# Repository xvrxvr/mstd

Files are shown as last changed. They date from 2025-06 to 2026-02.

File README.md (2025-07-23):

# UKNC-BK MSTD+

**UKNC-BK MSTD+** is a universal external mass storage device designed to work simultaneously with two Soviet-era 16-bit computers from the 1980s: the *Elektronika BK0010/0011* and the *Elektronika MS0511 (UKNC)*.

<https://en.wikipedia.org/wiki/Electronika_BK>

<https://en.wikipedia.org/wiki/UKNC>

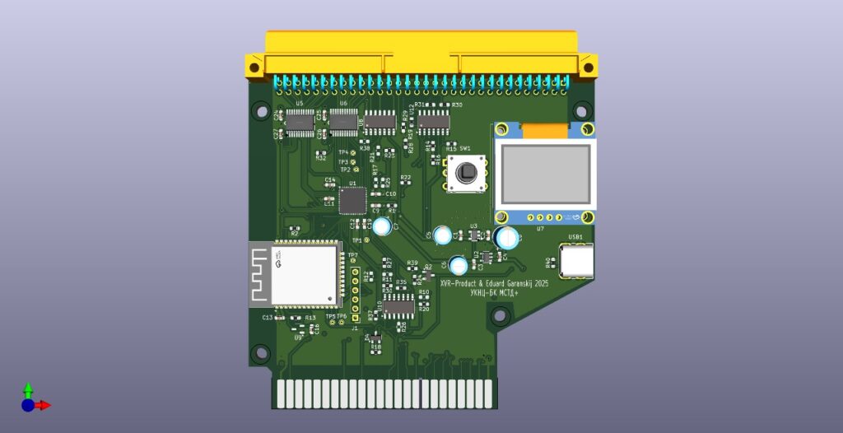
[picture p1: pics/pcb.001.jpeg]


Both machines are based on the K1801 series CPUs, which are compatible with the DEC PDP-11 instruction set and use a simplified version of the DEC UNIBUS-like MPI system bus.\
[Wiki MPI BUS (In Russian)](https://ru.wikipedia.org/wiki/%D0%9C%D0%B0%D0%B3%D0%B8%D1%81%D1%82%D1%80%D0%B0%D0%BB%D1%8C%D0%BD%D1%8B%D0%B9_%D0%BF%D0%B0%D1%80%D0%B0%D0%BB%D0%BB%D0%B5%D0%BB%D1%8C%D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)

While the physical connectors differ between the two systems (UKNC using an extended version), they are logically compatible.

To accommodate both, the board features two separate bus connectors—one for each computer.

**Key Features**

*	**Hardware**: Built on an ICE40UP5K FPGA and an ESP32 microcontroller.
*	**Display**: Includes a small OLED screen for disk image selection and device configuration.
*	**Storage**: Does **not** use SD cards. Disk images are uploaded via **Wi-Fi** and stored in the device’s internal Flash memory.
*	**Power**: USB-C connector is used **only for additional power supply**.
*	**Compatibility**: Works with both BK0010/BK0011 and UKNC (MS0511) computers.

**Current Status (July 2027)**

*	Custom PCB designed in KiCad
*	Hardware assembly and testing in progress\
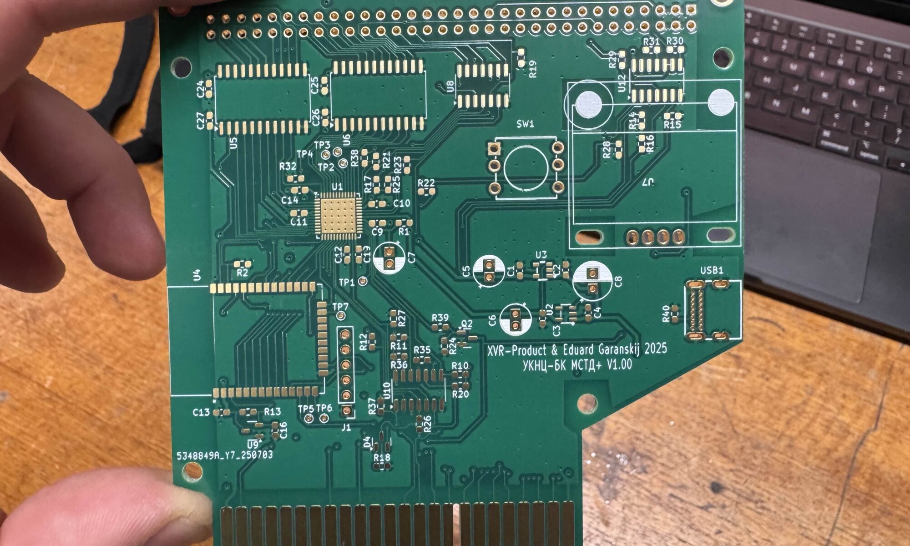
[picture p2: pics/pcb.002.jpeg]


# **Additional Resources**

##	📺 **Elektronika MS0511 (UKNC) Review**

*The Clueless Engineer*

[Watch on YouTube](https://www.youtube.com/watch?v=qSb77XoAgPw&ab_channel=TheCluelessEngineer)

##	📚 **DEC PDP-11 Instruction Set Reference**

Official DEC documentation archive

[View PDF](https://www.bitsavers.org/pdf/dec/pdp11/handbooks/PDP11_Handbook_1981.pdf)

##	🖥️ **UKNC Emulator**

Cross-platform emulator for Elektronika MS0511

[GitHub Repository](https://github.com/sergev/ukncbtl)

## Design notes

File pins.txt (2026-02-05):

ESP32

IO36 - Sensor-VP - CI0 Left
IO39 - Sensor-VN - CI1 Hit
IO34 - CI2             Up
IO35 - CI3             Right
IO32 - CIO0            Down

IO33 - CIO1            I2C-SCL
IO25 - CIO2            I2C-SDA

IO26 - CIO3            ROM-DIS3 (MON)   OUT  (1 - disable)
IO27 - CIO4            S-UKNC           IN
IO13 - CIO5            ROM-DIS1 (BAS)   OUT  (1 - disable)
IO21 - CIO6            S-BK             IN
IO19 - CIO7            ROM-DIS2 (BAS3)  OUT  (1 - disable)

    ESP -> FPGA
IO23 - CDONE           FPGA -> ESP32   (OC)
IO22 - ~CRESET         ESP32 -> FPGA
IO18 - IOB-29b
IO5  - IOB-31b
IO17 - IOB-32a-SPI_SO
IO16 - IPB-33b-SPI_SI
IO4  - IOB-34a-SPI_SCK
IO2  - IOB-35b-SPI_SS

FPGA
IOB-13b - FIO0            D3
IOB-16a - FIO1            D2
IOB-18a - FIO2            D1
IOB-20a - FIO3            D0
IOB-22a - FIO4            T/~R    OUT  [0 - read (BK -> FPGA), 1 - write (FPGA -> BK)]
IOB-23b - FIO5            WTB     IN
IOB-24a - FIO6            RUN     OUT  (1 - active)
ION-25b-G3 - FIO7         CE3     IN
IOB-0a                    D9
IOB-2a                    D8
IOB-3b-G6                 D11
IOB-4a                    D7
IOB-5b                    D10
IOB-6a                    D6
IOB-8a                    D4
IOB-9b                    D5

IOT-37a        INIT        OUT   (1 - reset)
IOT-38b        ROM-CE1     IN
IOT-39a        ROM-CE2     IN
IOT-41a        IRQ         OUT   (1 - IRQ)
IOT-42b        RPLY        OUT   (1 - Replay strobe)
IOT-43a        DOUT        IN
IOT-44b        DIN         IN
IOT-45a-G1     SYNC        IN
IOT-46b-G0     IAKN        IN
IOT-48b        D15
IOT-49a        D12
IOT-50b        D14
IOT-51a        D13

=======================================
FPGA config (pp31-34):

1. CRESET <= 0, SPI_SS <= 0, SPI_SCK <= 1
2. wait 200nS
3. CRESET <= 1
4. wait > 1.2mS (no SCK)
5. SPI_SS <= 1
6. Run SCK for 8 ticks
7. SPI_SS <= 0
8. Send data:
    MSB first, on faling edge of SCK
9. SPI_SS <= 1
10. wait for CDONE => 1  (still generating clocks). Max 100 clocks
11. send 49 more SCK ticks

SCK Freq - 1-25 MHz
=======================================

C sensor (5 wire flat cable) - 100-130pF/50cm (dry). Wet 130->330 pF
C sensor (PCB) - 270pF

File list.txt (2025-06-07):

iCE40UP5K-SG48I        C2678152  1340 6.5/1, 5.53/10

ESP32-WROOM-32E-N16    C701343   1774 4.4/1, 3.83/10
ESP32-WROOM-32D-N16    C529578   1148 4.3/1, 3.72/10

ESP32-S3-WROOM-1-N16R2 C2913205  4460 5.8/1, 4.86/10
ESP32-S3-WROOM-1-N16   C2913199   465 5.3/1, 4.5/10

LDO 1.2:
JTD6206-12             C42443422 2050  0.0067/50
LR8103A-T12            C7501644  53440 0.0218/20
TLV70212DBVR           C81462    28635 0.1031/5, 0.0807/50

LDO 3.3:    (500mA - 0.85W)
4A2D (CE is Hi)        C2832127  23920 0.0299/20, 500mA
TMI6050-33 (CE is Hi)  C911079   1698  0.0333/3, 0.0268/30  600mA   0.6W   (1.1W on 3x5 sm PCB)     <<<
AP7361C-33Y5-13        C460397   1115  0.1755/5  1.5A, 0.8W

SW:
HX809TDBZRG            C5145364  4240  0.0306/20

СНП58-64/94x9В-23-2-В (вилка)

74HCT4066D,118         C5998 4245  0.24/5

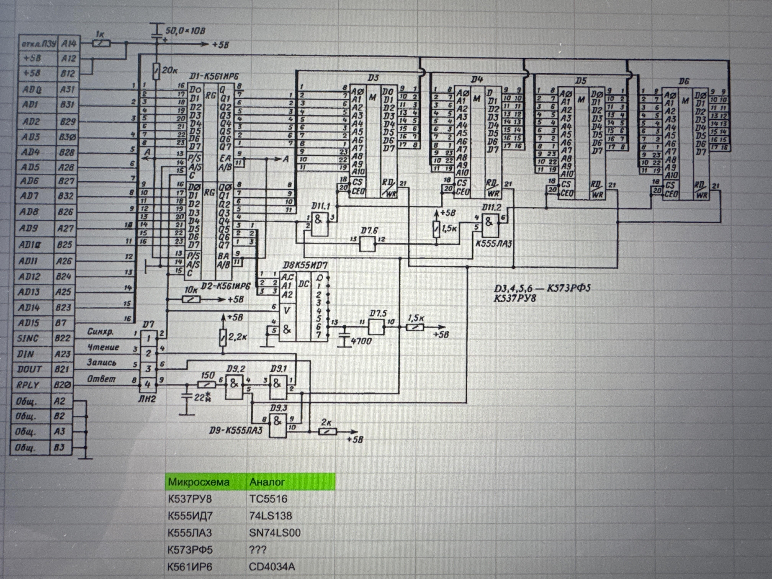
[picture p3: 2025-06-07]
mstd.jpg

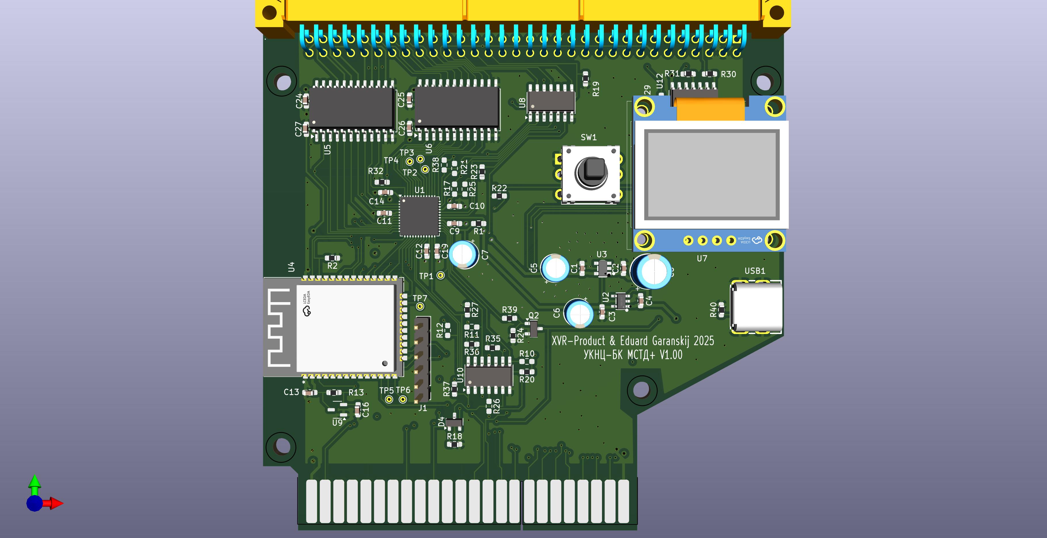
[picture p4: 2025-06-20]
mstd/mstd.jpg

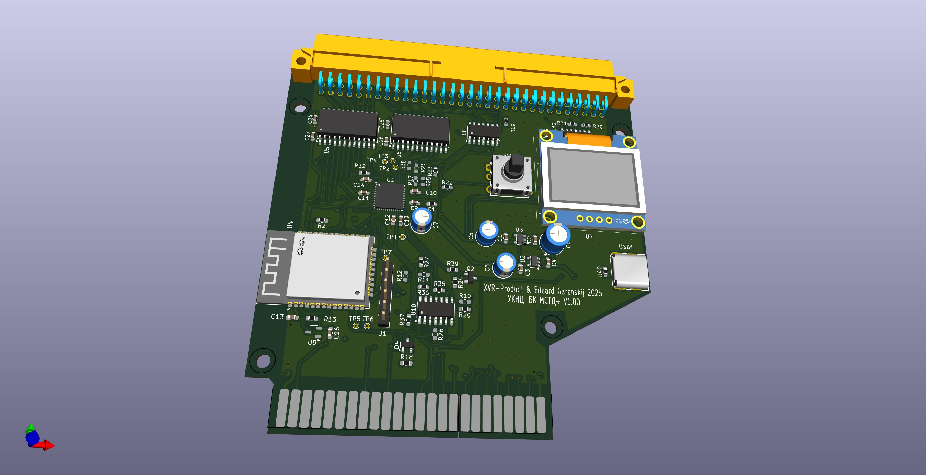
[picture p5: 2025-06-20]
mstd/mstd1.jpg

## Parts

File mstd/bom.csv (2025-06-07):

Reference | Value | Qty | DNP
C1,C2,C3,C4,C9,C10,C11,C12,C13,C14,C17,C19,C22,C23,C24,C25,C26,C27 | 1.0 | 18
C5 | 20x16V | 1
C6,C7 | 10x16V | 2
C8 | 100x16V | 1
C20 | 10.0x16V | 1
D4 | BAT54C | 1
J1 | PROG | 1
J2 | Barrel_Jack | 1
Q1 | SI2301CDS-T1-GE3 | 1
Q2 | 2N7002 | 1
R1 | 100 | 1
R2,R5,R6,R7,R8,R9,R13,R20,R22 | 10K | 9
R3,R4 | 2K2 | 2
R10,R11,R12,R17,R21,R25,R26,R38 | 1K | 8 | DNP
R14,R15,R16,R18,R19,R23,R24,R27,R28,R32,R34,R35,R36,R37 | 100K | 14
R29,R30,R31 | R | 3
R33 | 1K | 1
R39 | 200 | 1
SW1 | TSX101G100-250 | 1
U1 | ICE40UP5K-SG48ITR | 1
U2 | TLV70212DBVR | 1
U3 | TMI6050-33 | 1
U4 | ESP32-WROOM-32E-N16 | 1
U5,U6 | 74LVX3245MTCX | 2
U7 | SSD1306 OLED | 1
U8,U10 | 74HCT05 | 2
U9 | APX803S-31SA | 1 | DNP
U12 | 74HCT4066 | 1
X3,X4 | ~ | 2

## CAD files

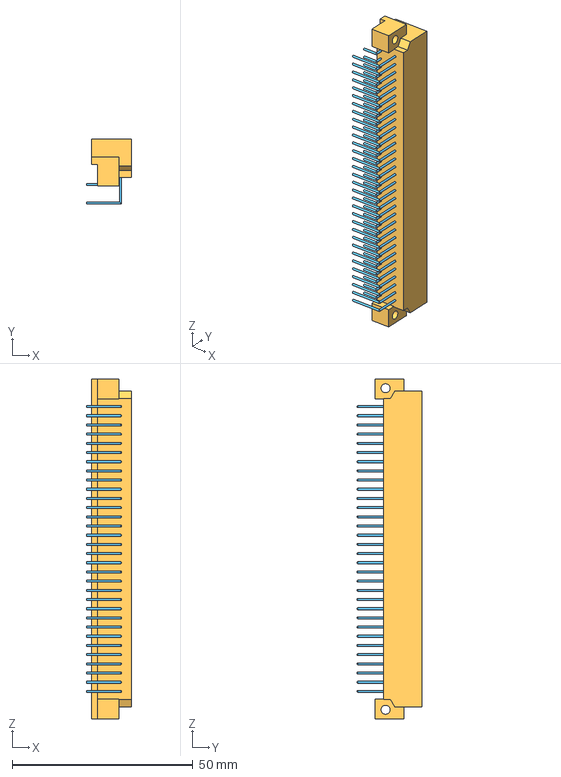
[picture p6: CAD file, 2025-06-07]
mstd/3D/09031646951.stp
12.4 x 18.0 x 94.0 mm

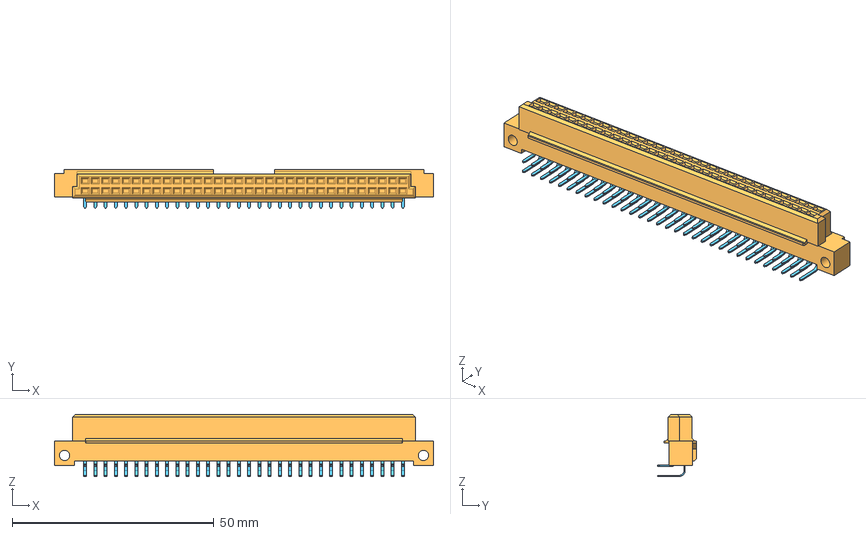
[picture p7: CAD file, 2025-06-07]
mstd/3D/09722646801.stp
93.9 x 9.59 x 15.4 mm

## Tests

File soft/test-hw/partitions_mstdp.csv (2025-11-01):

# Name | Type | SubType | Offset | Size | Flags
# Note: if you have increased the bootloader size | make sure to update the offsets to avoid overlap
nvs | data | nvs | 0x9000 | 0x6000
phy_init | data | phy | 0xf000 | 0x1000
otadata | data | ota | 0x10000 | 0x2000
config | data | undefined | 0x12000 | 0x1000
# Hole
loader | app | test |  | 1M
ota_0 | app | ota_0 |  | 3M
ota_1 | app | ota_1 |  | 3M
storage | data | spiffs |  | -16M

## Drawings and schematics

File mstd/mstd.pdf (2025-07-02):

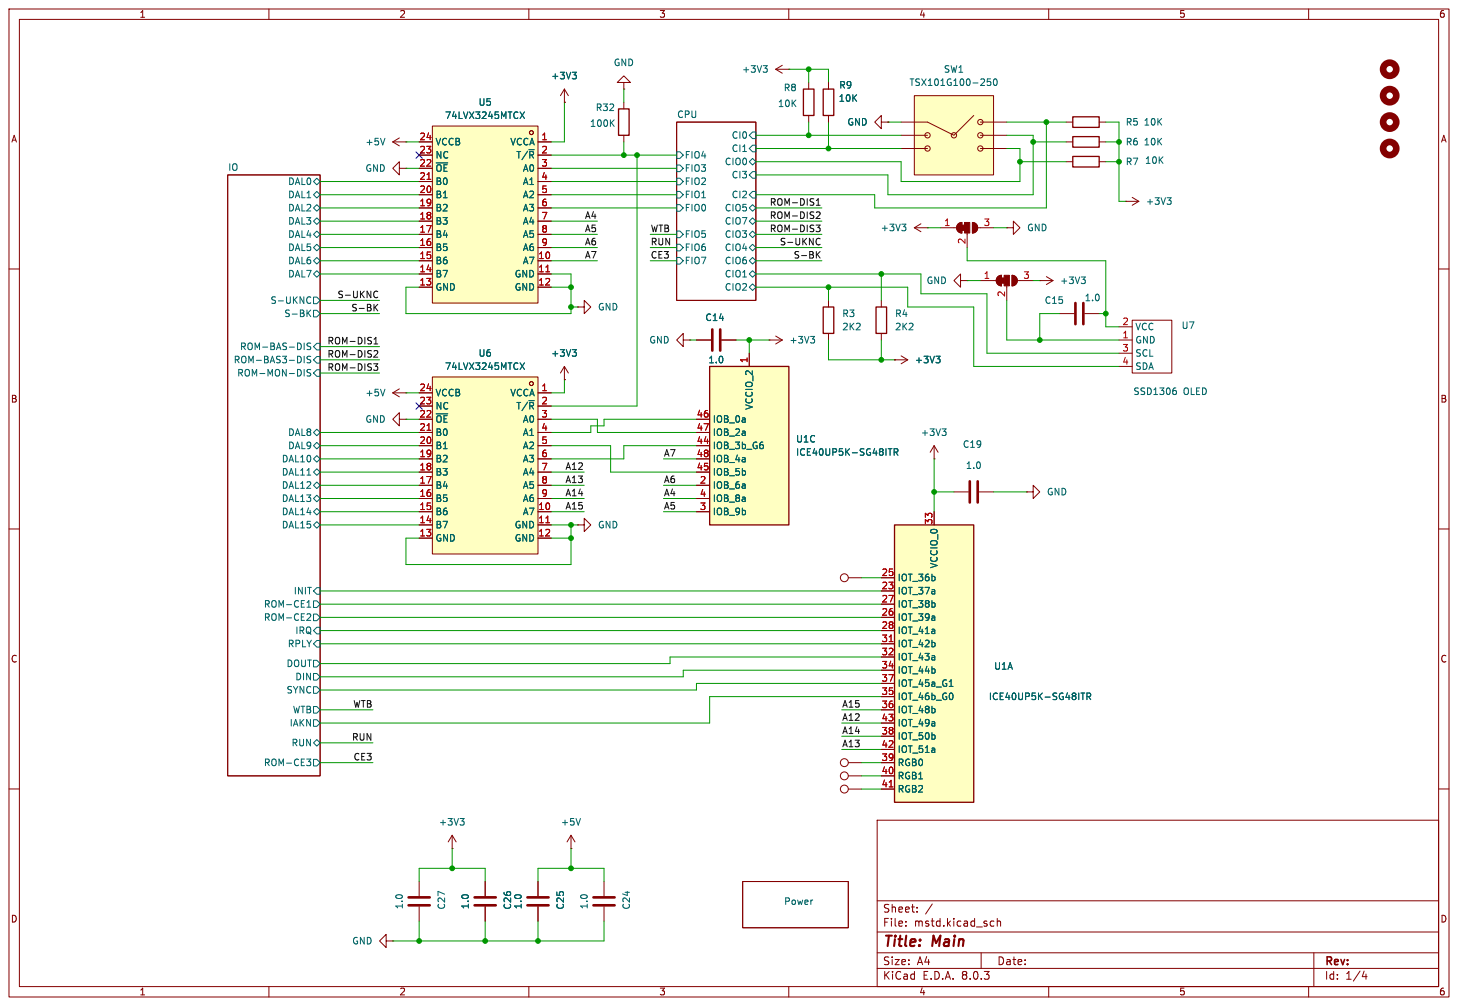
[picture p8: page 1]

File: mstd.kicad_sch Sheet: / Power RPLY WTB DAL6 DAL7 DAL4 DAL3 DAL5 DAL0 DAL2 DAL1 DAL9 DAL10 DAL11 DAL12 DAL8

DOUT ROM-MON-DIS ROM-CE1 ROM-CE2 ROM-CE3 ROM-BAS3-DIS ROM-BAS-DISRUN

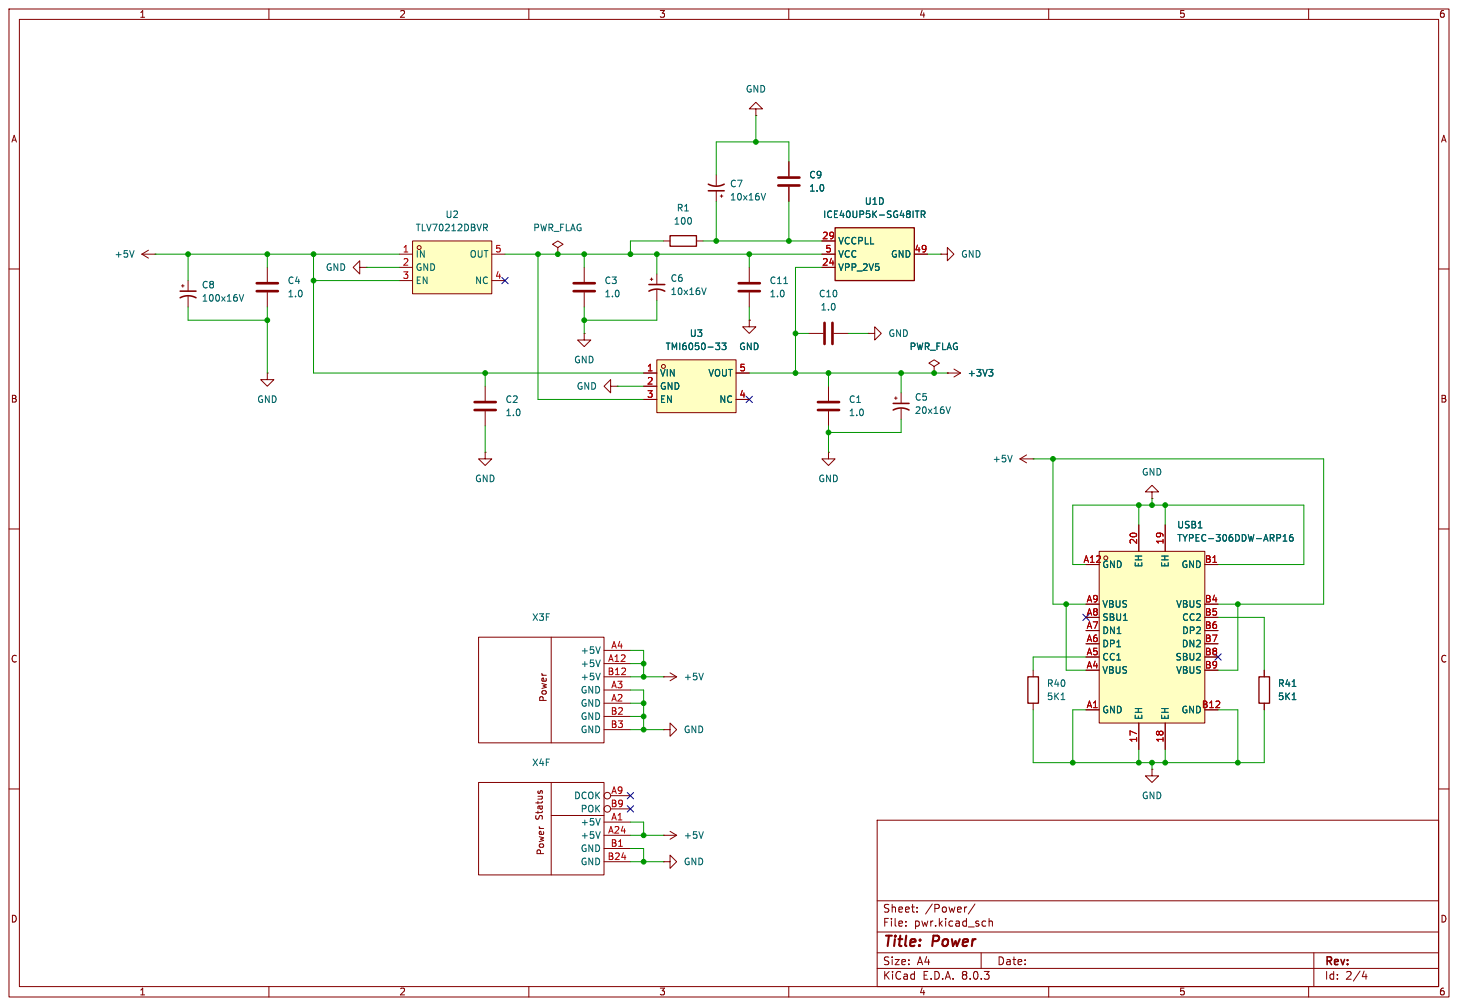
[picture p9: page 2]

Id: 2/4 Title: Power File: pwr.kicad_sch Sheet: /Power/

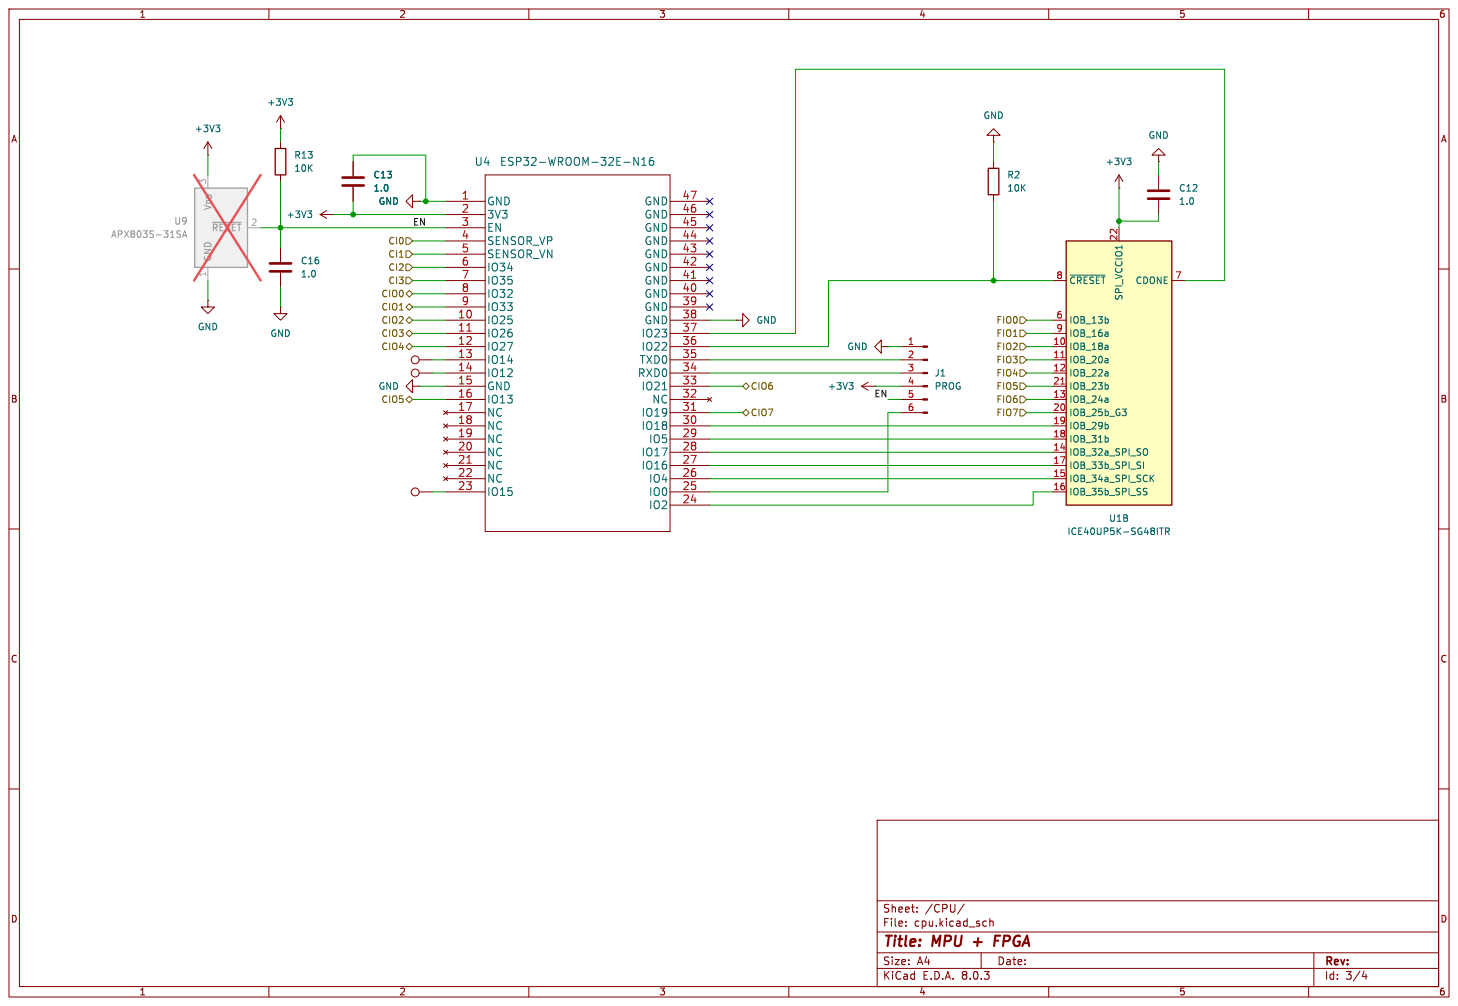
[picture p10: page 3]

File: cpu.kicad_sch Sheet: /CPU/
Id: 3/4 Title: MPU + FPGA

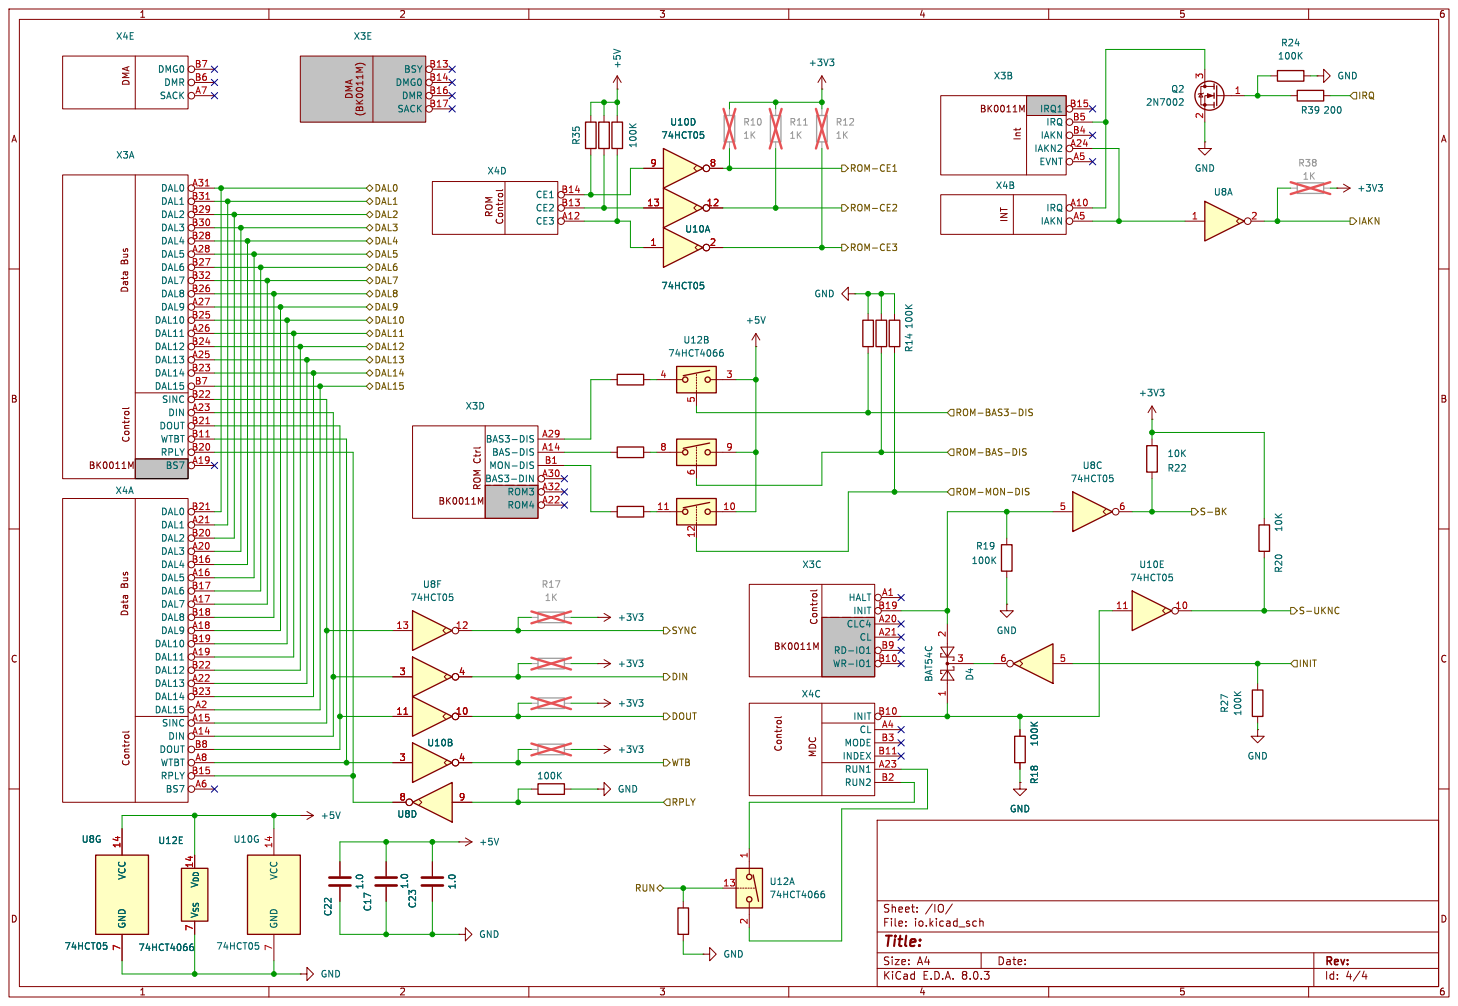
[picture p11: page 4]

Id: 4/4 Title: File: io.kicad_sch Sheet: /IO/ VCC 14 GND 7 U8G

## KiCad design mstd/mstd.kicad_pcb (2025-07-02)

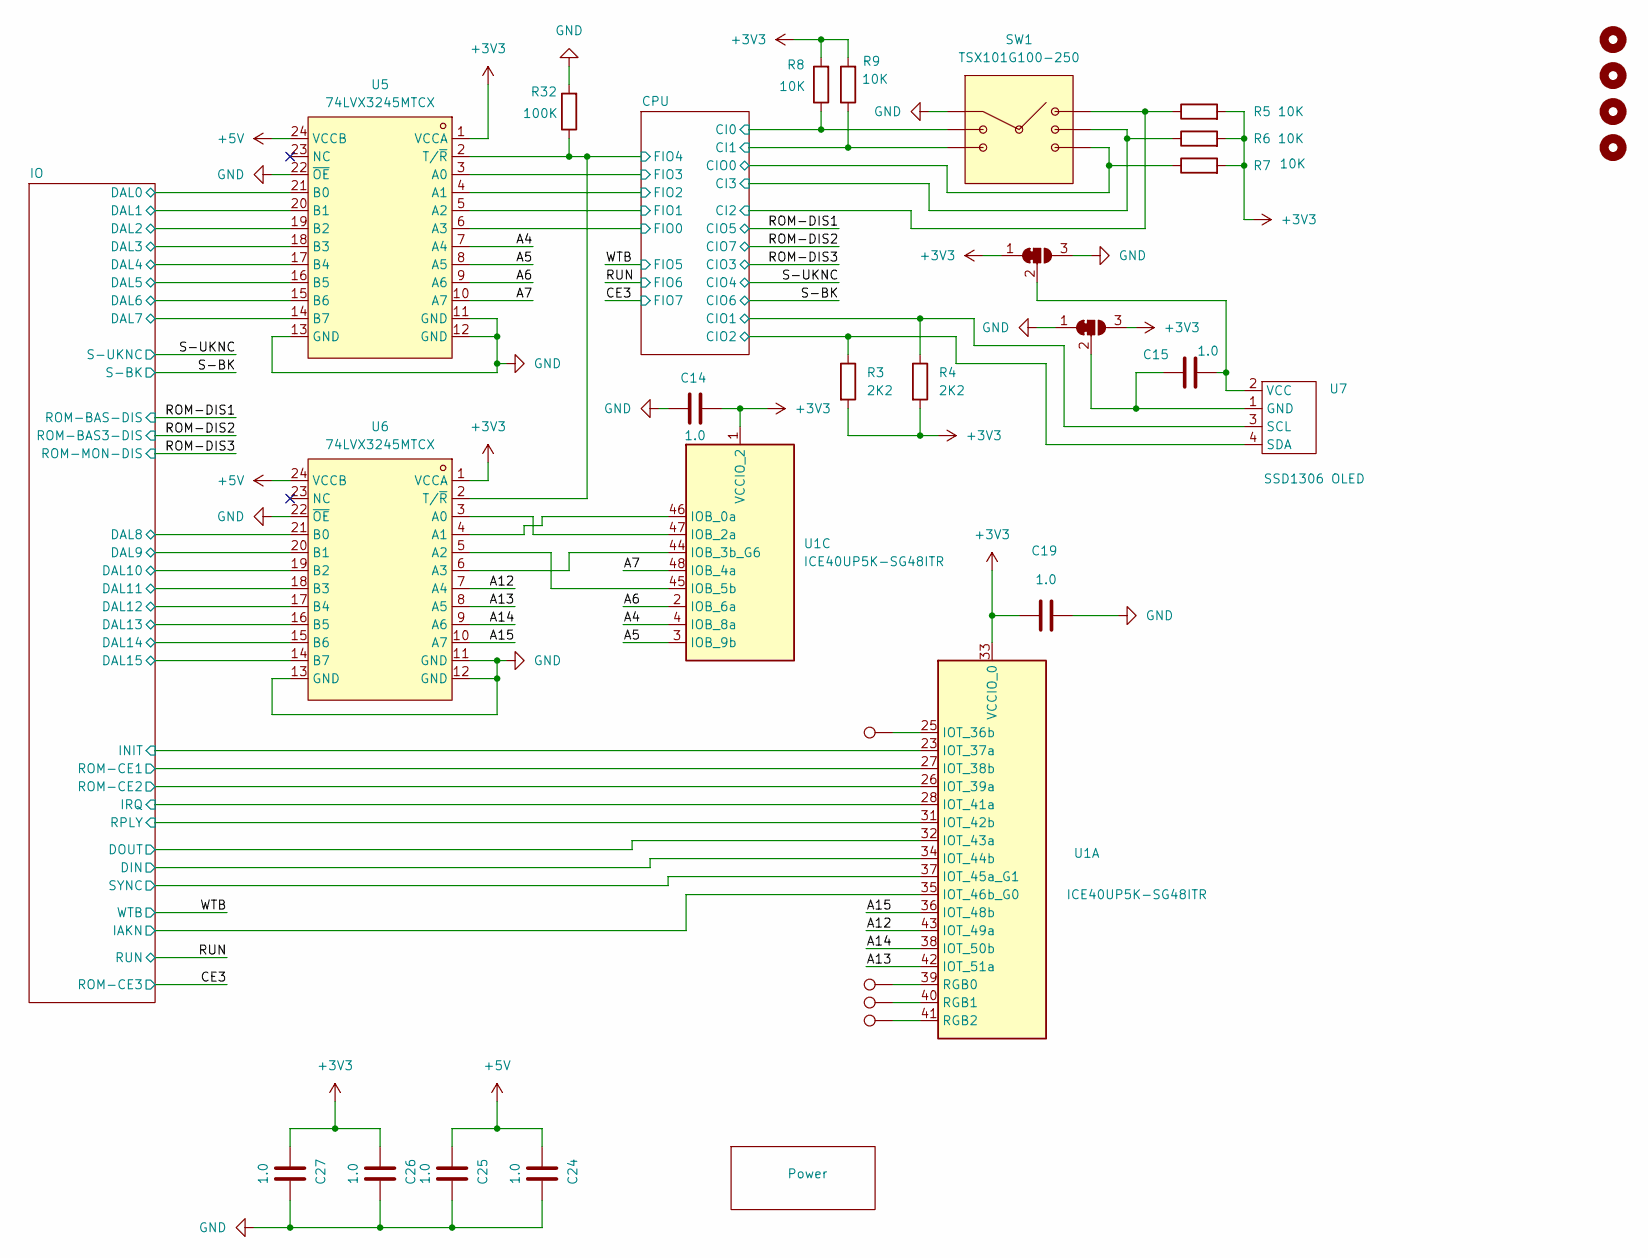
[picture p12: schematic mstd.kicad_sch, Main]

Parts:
C14, C15, C19, C24, C25, C26, C27: 1.0; C_0603_1608Metric_Pad1.08x0.95mm_HandSolder
H1, H2, H3, H4: MountingHole; MountingHole_3.2mm_M3_ISO14580
JP1, JP2: SolderJumper_3_Bridged12; SolderJumper-3_P1.3mm_Bridged12_RoundedPad1.0x1.5mm
R3, R4: 2K2; R_0603_1608Metric_Pad0.98x0.95mm_HandSolder
R5, R6, R7, R8, R9: 10K; R_0603_1608Metric_Pad0.98x0.95mm_HandSolder
R32: 100K; R_0603_1608Metric_Pad0.98x0.95mm_HandSolder
SW1: TSX101G100-250; SW-TH_TSX101G100-250; LCSC Part C722957
TP1, TP2, TP3, TP4: TestPoint; TestPoint_THTPad_D1.0mm_Drill0.5mm
U1: ICE40UP5K-SG48ITR; QFN-48-1EP_7x7mm_P0.5mm_EP5.6x5.6mm
U5, U6: 74LVX3245MTCX; SOP-24_7.5x15.4mm_P1.27mm; LCSC Part C6135
U7: SSD1306 OLED; SDD1306

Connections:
+3V3: C14.2, C19.1, C26.1, C27.1, JP1.1 (A), JP2.3 (B), R3.2, R4.2, R5.2, R6.2, R7.2, R8.2, R9.2, U1.1 (VCCIO_2), U1.33 (VCCIO_0), U5.1 (VCCA), U6.1 (VCCA); also elsewhere on the board
+5V: C24.1, C25.1, U5.24 (VCCB), U6.24 (VCCB); also elsewhere on the board
/A4: U1.4 (IOB_8a), U5.7 (A4)
/A5: U1.3 (IOB_9b), U5.8 (A5)
/A6: U1.2 (IOB_6a), U5.9 (A6)
/A7: U1.48 (IOB_4a), U5.10 (A7)
/A12: U1.43 (IOT_49a), U6.7 (A4)
/A13: U1.42 (IOT_51a), U6.8 (A5)
/A14: U1.38 (IOT_50b), U6.9 (A6)
/A15: U1.36 (IOT_48b), U6.10 (A7)
/CPU/CI0: R8.1, SW1.2; also elsewhere on the board
/CPU/CI1: R9.1, SW1.3; also elsewhere on the board
/CPU/CI2: R5.1, SW1.4; also elsewhere on the board
/CPU/CI3: R6.1, SW1.5; also elsewhere on the board
/CPU/CIO0: R7.1, SW1.6; also elsewhere on the board
/CPU/CIO1: R4.1, U7.3 (SCL); also elsewhere on the board
/CPU/CIO2: R3.1, U7.4 (SDA); also elsewhere on the board
/CPU/FIO0: U5.6 (A3); also elsewhere on the board
/CPU/FIO1: U5.5 (A2); also elsewhere on the board
/CPU/FIO2: U5.4 (A1); also elsewhere on the board
/CPU/FIO3: U5.3 (A0); also elsewhere on the board
/CPU/FIO4: R32.1, U5.2 (T/~R), U6.2 (T/~R); also elsewhere on the board
/IO/DAL0: U5.21 (B0); also elsewhere on the board
/IO/DAL1: U5.20 (B1); also elsewhere on the board
/IO/DAL2: U5.19 (B2); also elsewhere on the board
/IO/DAL3: U5.18 (B3); also elsewhere on the board
/IO/DAL4: U5.17 (B4); also elsewhere on the board
/IO/DAL5: U5.16 (B5); also elsewhere on the board
/IO/DAL6: U5.15 (B6); also elsewhere on the board
/IO/DAL7: U5.14 (B7); also elsewhere on the board
/IO/DAL8: U6.21 (B0); also elsewhere on the board
/IO/DAL9: U6.20 (B1); also elsewhere on the board
/IO/DAL10: U6.19 (B2); also elsewhere on the board
/IO/DAL11: U6.18 (B3); also elsewhere on the board
/IO/DAL12: U6.17 (B4); also elsewhere on the board
/IO/DAL13: U6.16 (B5); also elsewhere on the board
/IO/DAL14: U6.15 (B6); also elsewhere on the board
/IO/DAL15: U6.14 (B7); also elsewhere on the board
/IO/DIN: U1.34 (IOT_44b); also elsewhere on the board
/IO/DOUT: U1.32 (IOT_43a); also elsewhere on the board
/IO/IAKN: U1.35 (IOT_46b_G0); also elsewhere on the board
/IO/INIT: U1.23 (IOT_37a); also elsewhere on the board
/IO/IRQ: U1.28 (IOT_41a); also elsewhere on the board
/IO/ROM-CE1: U1.27 (IOT_38b); also elsewhere on the board
/IO/ROM-CE2: U1.26 (IOT_39a); also elsewhere on the board
/IO/RPLY: U1.31 (IOT_42b); also elsewhere on the board
/IO/SYNC: U1.37 (IOT_45a_G1); also elsewhere on the board
GND: C14.1, C19.2, C24.2, C25.2, C26.2, C27.2, JP1.3 (B), JP2.1 (A), R32.2, SW1.1, U5.11 (GND), U5.12 (GND), U5.13 (GND), U5.22 (~OE), U6.11 (GND), U6.12 (GND), U6.13 (GND), U6.22 (~OE); also elsewhere on the board
unnamed: C15.2, JP1.2 (C), U7.2 (VCC)
unnamed: C15.1, JP2.2 (C), U7.1 (GND)
unnamed: TP1.1, U1.25 (IOT_36b)
unnamed: TP2.1, U1.39 (RGB0)
unnamed: TP3.1, U1.40 (RGB1)
unnamed: TP4.1, U1.41 (RGB2)
unnamed: U1.46 (IOB_0a), U6.4 (A1)
unnamed: U1.47 (IOB_2a), U6.3 (A0)
unnamed: U1.44 (IOB_3b_G6), U6.6 (A3)
unnamed: U1.45 (IOB_5b), U6.5 (A2)

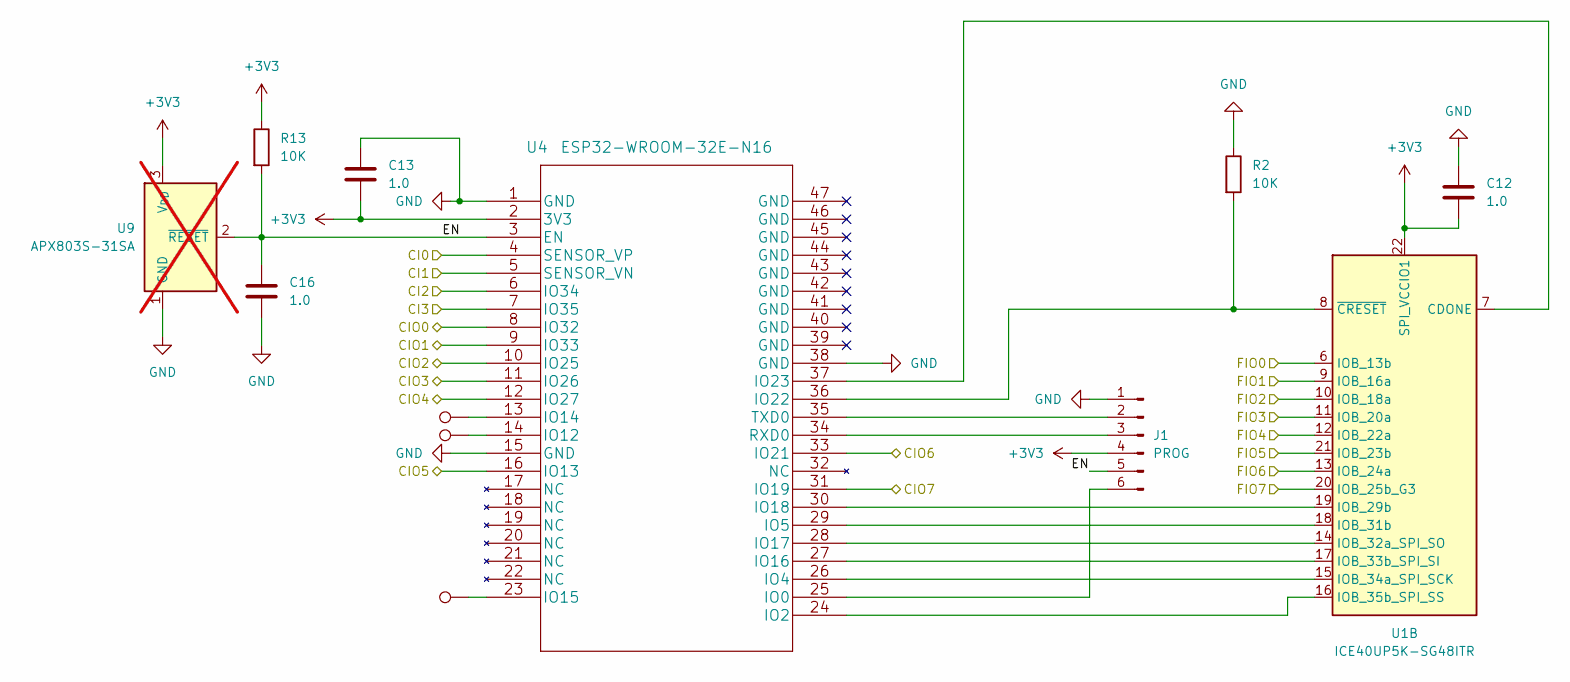
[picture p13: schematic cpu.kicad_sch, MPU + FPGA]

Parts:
C12, C13, C16: 1.0; C_0603_1608Metric_Pad1.08x0.95mm_HandSolder
J1: PROG; PinHeader_1x06_P2.54mm_Vertical
R2, R13: 10K; R_0603_1608Metric_Pad0.98x0.95mm_HandSolder
TP5, TP6, TP7: TestPoint; TestPoint_THTPad_D1.0mm_Drill0.5mm
U1: ICE40UP5K-SG48ITR; QFN-48-1EP_7x7mm_P0.5mm_EP5.6x5.6mm
U4: ESP32-WROOM-32E-N16; ESP32-WROOM-32E-N8
U9: APX803S-31SA; SOT-23-3; not fitted

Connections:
+3V3: C12.2, C13.2, J1.4, R13.1, U1.22 (SPI_VCCIO1), U4.2 (3V3), U9.3 (V_{DD}); also elsewhere on the board
/CE3: U1.20 (IOB_25b_G3); also elsewhere on the board
/CPU/CI0: U4.4 (SENSOR_VP); also elsewhere on the board
/CPU/CI1: U4.5 (SENSOR_VN); also elsewhere on the board
/CPU/CI2: U4.6 (IO34); also elsewhere on the board
/CPU/CI3: U4.7 (IO35); also elsewhere on the board
/CPU/CIO0: U4.8 (IO32); also elsewhere on the board
/CPU/CIO1: U4.9 (IO33); also elsewhere on the board
/CPU/CIO2: U4.10 (IO25); also elsewhere on the board
/CPU/EN: C16.1, J1.5, R13.2, U4.3 (EN), U9.2 (~RESET)
/CPU/FIO0: U1.6 (IOB_13b); also elsewhere on the board
/CPU/FIO1: U1.9 (IOB_16a); also elsewhere on the board
/CPU/FIO2: U1.10 (IOB_18a); also elsewhere on the board
/CPU/FIO3: U1.11 (IOB_20a); also elsewhere on the board
/CPU/FIO4: U1.12 (IOB_22a); also elsewhere on the board
/ROM-DIS1: U4.16 (IO13); also elsewhere on the board
/ROM-DIS2: U4.31 (IO19); also elsewhere on the board
/ROM-DIS3: U4.11 (IO26); also elsewhere on the board
/RUN: U1.13 (IOB_24a); also elsewhere on the board
/S-BK: U4.33 (IO21); also elsewhere on the board
/S-UKNC: U4.12 (IO27); also elsewhere on the board
/WTB: U1.21 (IOB_23b); also elsewhere on the board
GND: C12.1, C13.1, C16.2, J1.1, R2.1, U4.1 (GND), U4.15 (GND), U4.38 (GND), U9.1 (GND); also elsewhere on the board
unnamed: J1.2, U4.35 (TXD0)
unnamed: J1.3, U4.34 (RXD0)
unnamed: J1.6, U4.25 (IO0)
unnamed: U1.7 (CDONE), U4.37 (IO23)
unnamed: U1.19 (IOB_29b), U4.30 (IO18)
unnamed: U1.18 (IOB_31b), U4.29 (IO5)
unnamed: U1.14 (IOB_32a_SPI_SO), U4.28 (IO17)
unnamed: U1.17 (IOB_33b_SPI_SI), U4.27 (IO16)
unnamed: U1.15 (IOB_34a_SPI_SCK), U4.26 (IO4)
unnamed: U1.16 (IOB_35b_SPI_SS), U4.24 (IO2)
unnamed: R2.2, U1.8 (~CRESET), U4.36 (IO22)
unnamed: TP6.1, U4.14 (IO12)
unnamed: TP5.1, U4.13 (IO14)
unnamed: TP7.1, U4.23 (IO15)

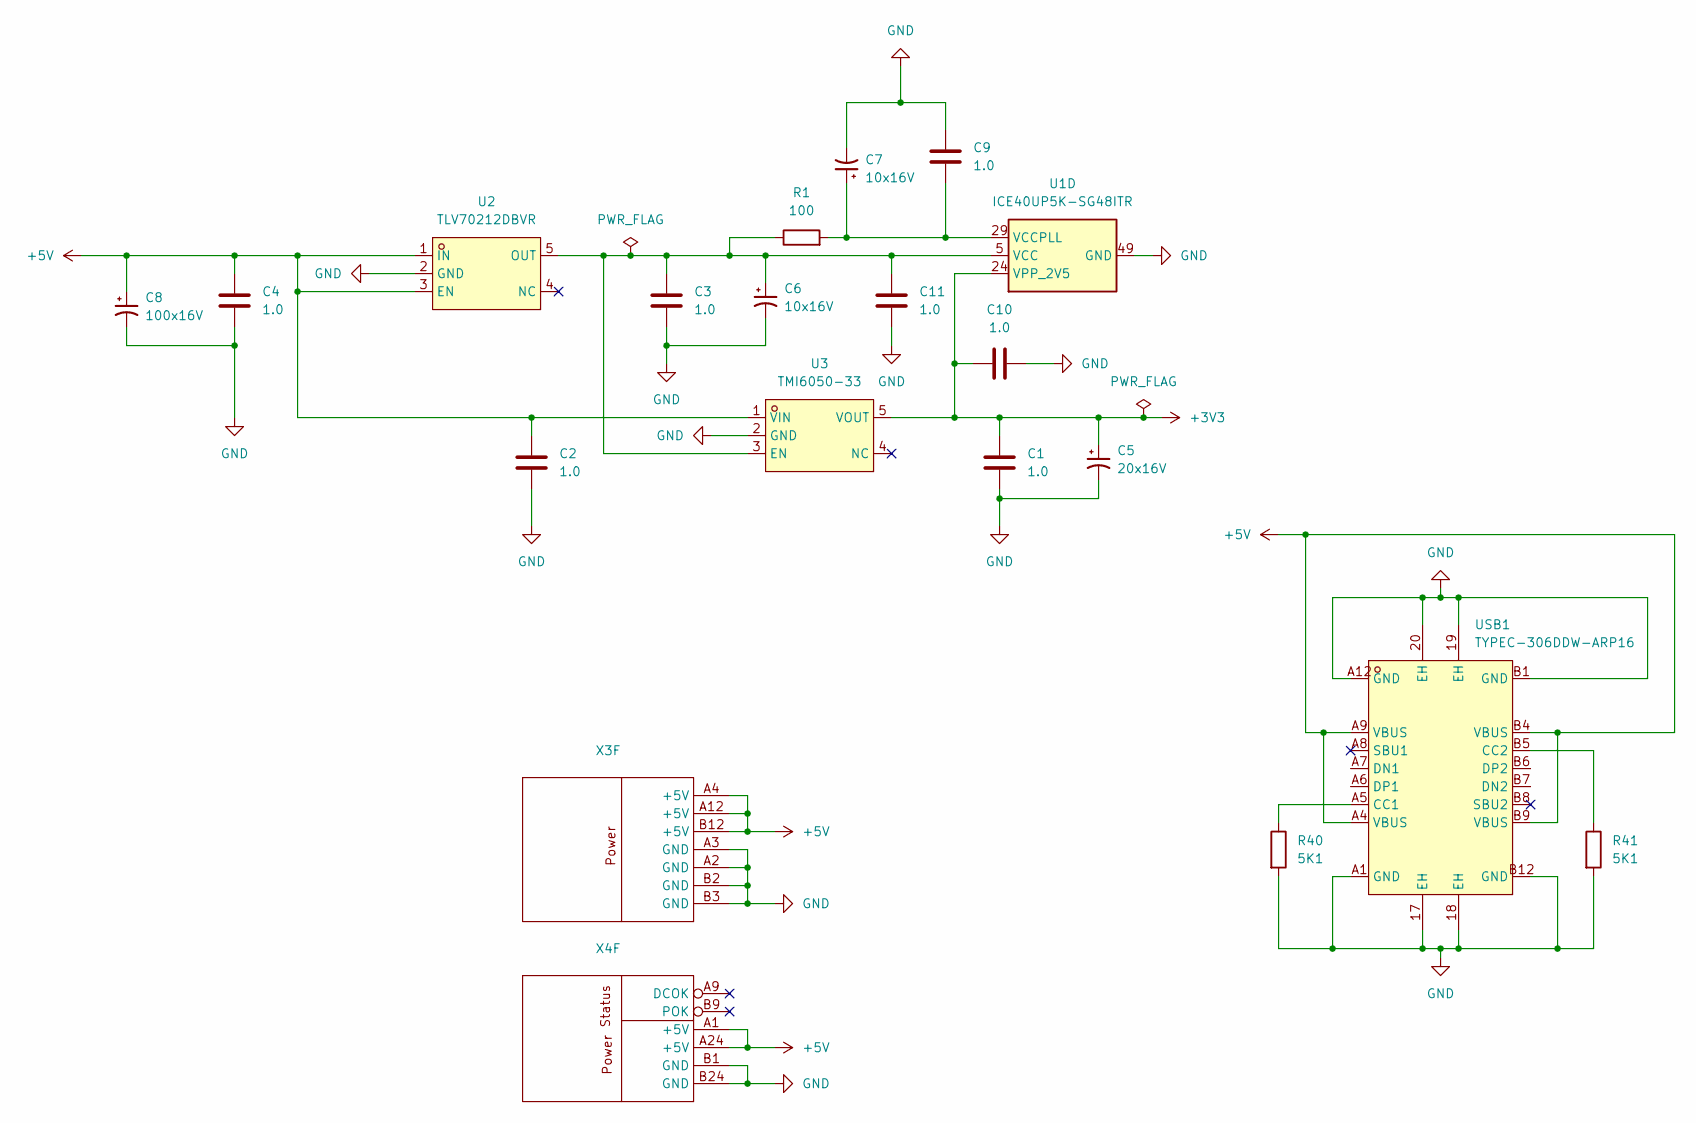
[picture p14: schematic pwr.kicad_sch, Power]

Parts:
C1, C2, C3, C4, C9, C10, C11: 1.0; C_0603_1608Metric_Pad1.08x0.95mm_HandSolder
C5: 20x16V; CP_Radial_D5.0mm_P2.00mm
C6, C7: 10x16V; CP_Radial_D5.0mm_P2.00mm
C8: 100x16V; CP_Radial_D6.3mm_P2.50mm
R1: 100; R_0603_1608Metric_Pad0.98x0.95mm_HandSolder
R40, R41: 5K1; R_0603_1608Metric_Pad0.98x0.95mm_HandSolder; LCSC Part C2907044
U1: ICE40UP5K-SG48ITR; QFN-48-1EP_7x7mm_P0.5mm_EP5.6x5.6mm
U2: TLV70212DBVR; SOT-23-5_L3.0-W1.7-P0.95-LS2.8-BL; LCSC Part C81462
U3: TMI6050-33; SOT-23-5_L2.9-W1.6-P0.95-LS2.8-BR; LCSC Part C911079
USB1: TYPEC-306DDW-ARP16; USB-C-TH_TYPEC-306DDW-ARP16; LCSC Part C2840393
X3: 09722642801-1
X4: snp15

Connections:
+3V3: C1.1, C5.1, C10.1, U1.24 (VPP_2V5), U3.5 (VOUT); also elsewhere on the board
+5V: C2.1, C4.1, C8.1, U2.1 (IN), U2.3 (EN), U3.1 (VIN), USB1.A4 (VBUS), USB1.A9 (VBUS), USB1.B4 (VBUS), USB1.B9 (VBUS), X3.A4 (+5V), X3.A12 (+5V), X3.B12 (+5V), X4.A1 (+5V), X4.A24 (+5V); also elsewhere on the board
GND: C1.2, C2.2, C3.2, C4.2, C5.2, C6.2, C7.2, C8.2, C9.1, C10.2, C11.2, R40.2, R41.2, U1.49 (GND), U2.2 (GND), U3.2 (GND), USB1.17 (EH), USB1.18 (EH), USB1.19 (EH), USB1.20 (EH), USB1.A1 (GND), USB1.A12 (GND), USB1.B1 (GND), USB1.B12 (GND), X3.A2 (GND), X3.A3 (GND), X3.B2 (GND), X3.B3 (GND), X4.B1 (GND), X4.B24 (GND); also elsewhere on the board
unnamed: C7.1, C9.2, R1.2, U1.29 (VCCPLL)
unnamed: C3.1, C6.1, C11.1, R1.1, U1.5 (VCC), U1.30 (VCC), U2.5 (OUT), U3.3 (EN)
unnamed: R40.1, USB1.A5 (CC1)
unnamed: R41.1, USB1.B5 (CC2)

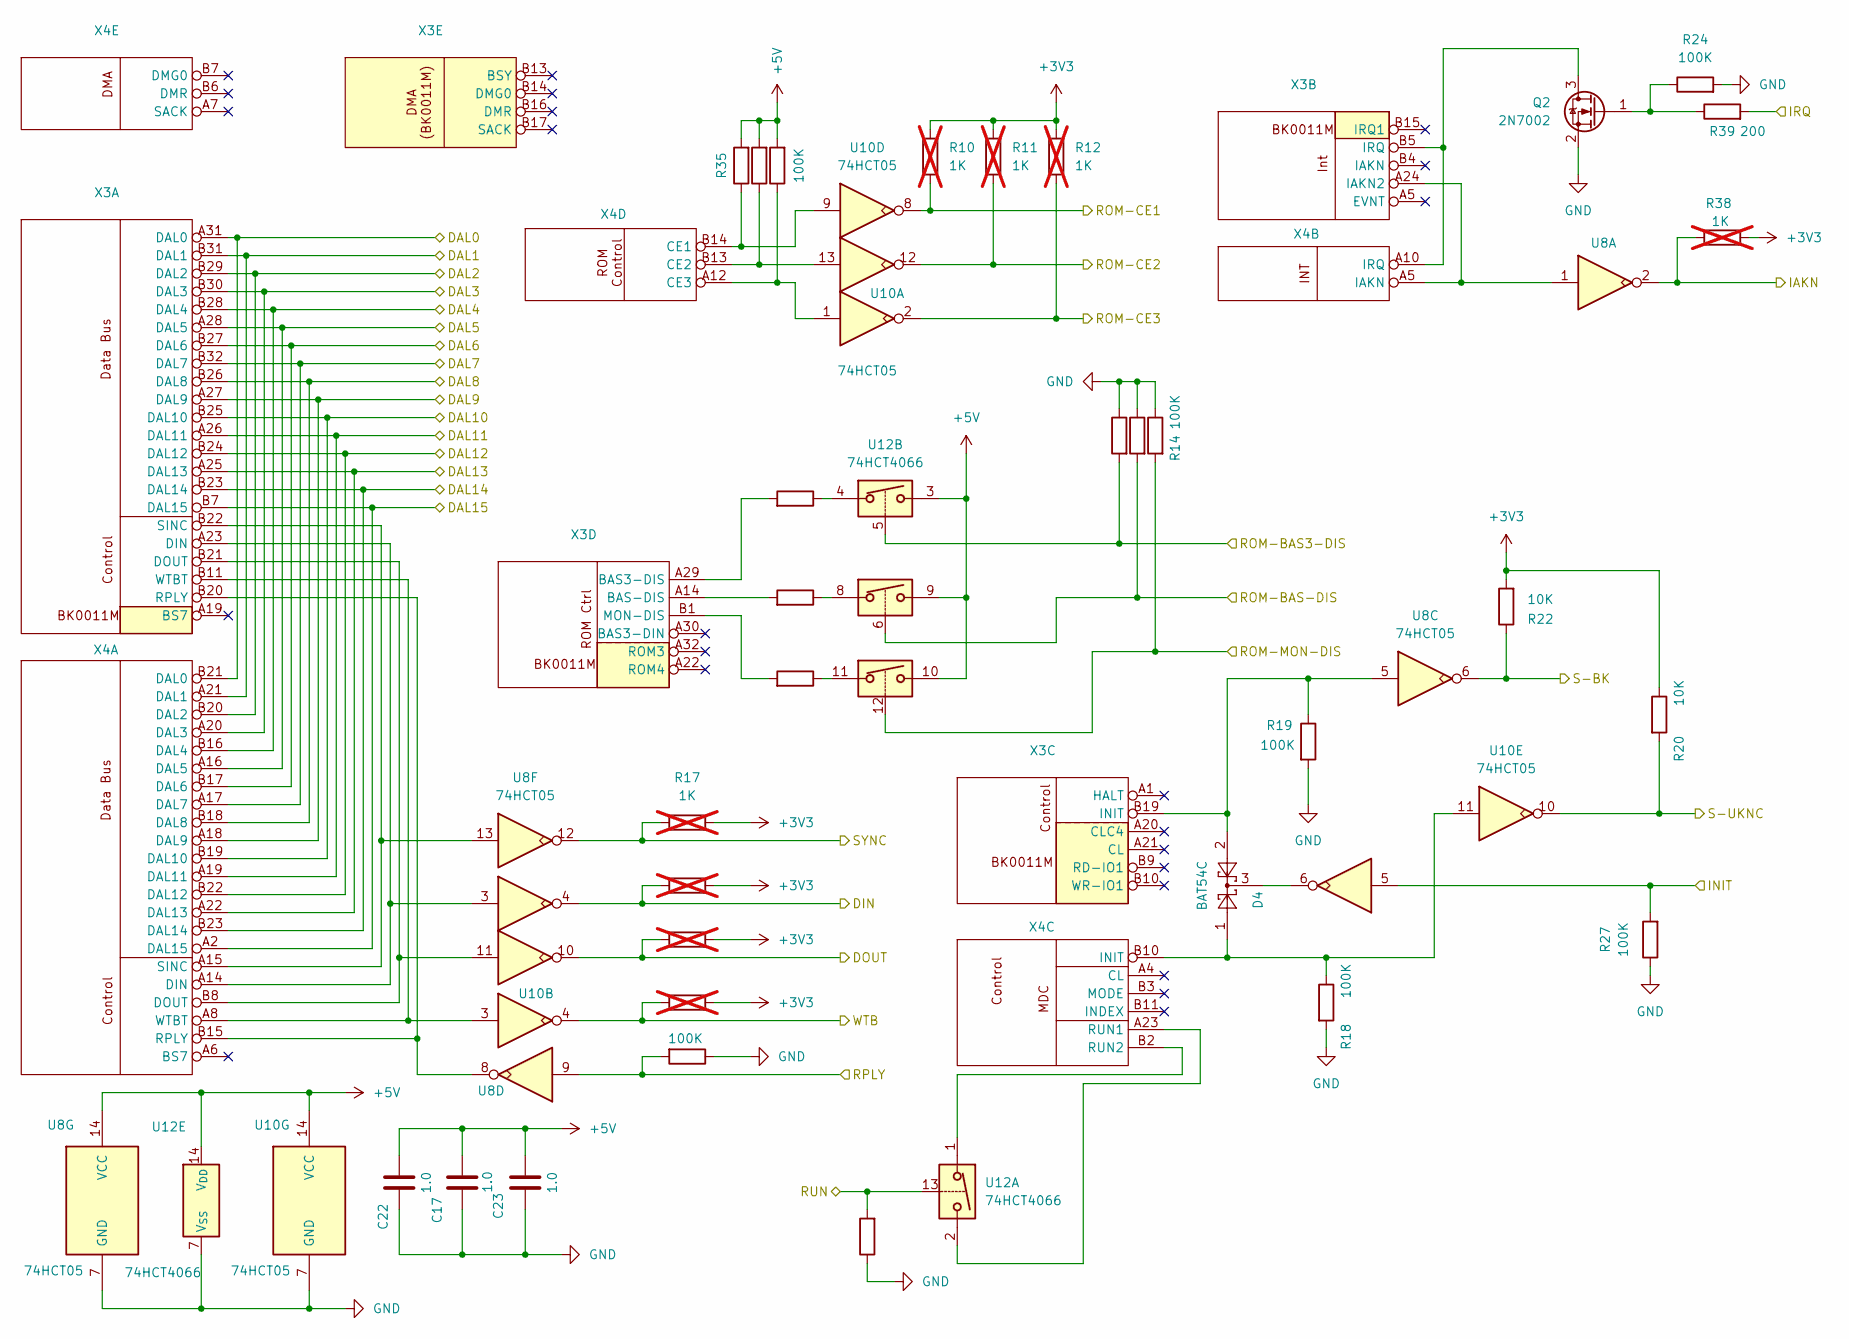
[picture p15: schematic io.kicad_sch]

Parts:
C17, C22, C23: 1.0; C_0603_1608Metric_Pad1.08x0.95mm_HandSolder
D4: BAT54C; SOT-23
Q2: 2N7002; SOT-23
R10, R11, R12, R17, R21, R25, R26, R38: 1K; R_0603_1608Metric_Pad0.98x0.95mm_HandSolder; not fitted
R14, R15, R16, R18, R19, R23, R24, R27, R28, R35, R36, R37: 100K; R_0603_1608Metric_Pad0.98x0.95mm_HandSolder
R20, R22: 10K; R_0603_1608Metric_Pad0.98x0.95mm_HandSolder
R29, R30, R31: R; R_0603_1608Metric_Pad0.98x0.95mm_HandSolder
R39: 200; R_0603_1608Metric_Pad0.98x0.95mm_HandSolder
U8, U10: 74HCT05; SO-14_3.9x8.65mm_P1.27mm
U12: 74HCT4066; SO-14_3.9x8.65mm_P1.27mm
X3: 09722642801-1
X4: snp15

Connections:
+3V3: R10.2, R11.2, R12.2, R17.2, R20.1, R21.2, R22.2, R25.2, R26.2, R38.1; also elsewhere on the board
+5V: C17.2, C22.2, C23.2, R35.2, R36.2, R37.2, U8.14 (VCC), U10.14 (VCC), U12.3, U12.9, U12.10, U12.14 (V_{DD}); also elsewhere on the board
/CE3: R12.1, U10.2; also elsewhere on the board
/IO/DAL0: X3.A31 (DAL0), X4.B21 (DAL0); also elsewhere on the board
/IO/DAL1: X3.B31 (DAL1), X4.A21 (DAL1); also elsewhere on the board
/IO/DAL2: X3.B29 (DAL2), X4.B20 (DAL2); also elsewhere on the board
/IO/DAL3: X3.B30 (DAL3), X4.A20 (DAL3); also elsewhere on the board
/IO/DAL4: X3.B28 (DAL4), X4.B16 (DAL4); also elsewhere on the board
/IO/DAL5: X3.A28 (DAL5), X4.A16 (DAL5); also elsewhere on the board
/IO/DAL6: X3.B27 (DAL6), X4.B17 (DAL6); also elsewhere on the board
/IO/DAL7: X3.B32 (DAL7), X4.A17 (DAL7); also elsewhere on the board
/IO/DAL8: X3.B26 (DAL8), X4.B18 (DAL8); also elsewhere on the board
/IO/DAL9: X3.A27 (DAL9), X4.A18 (DAL9); also elsewhere on the board
/IO/DAL10: X3.B25 (DAL10), X4.B19 (DAL10); also elsewhere on the board
/IO/DAL11: X3.A26 (DAL11), X4.A19 (DAL11); also elsewhere on the board
/IO/DAL12: X3.B24 (DAL12), X4.B22 (DAL12); also elsewhere on the board
/IO/DAL13: X3.A25 (DAL13), X4.A22 (DAL13); also elsewhere on the board
/IO/DAL14: X3.B23 (DAL14), X4.B23 (DAL14); also elsewhere on the board
/IO/DAL15: X3.B7 (DAL15), X4.A2 (DAL15); also elsewhere on the board
/IO/DIN: R21.1, U8.4; also elsewhere on the board
/IO/DOUT: R25.1, U8.10; also elsewhere on the board
/IO/IAKN: R38.2, U8.2; also elsewhere on the board
/IO/INIT: R27.2, U10.5; also elsewhere on the board
/IO/IRQ: R39.2; also elsewhere on the board
/IO/ROM-CE1: R10.1, U10.8; also elsewhere on the board
/IO/ROM-CE2: R11.1, U10.12; also elsewhere on the board
/IO/RPLY: R23.2, U8.9; also elsewhere on the board
/IO/SYNC: R17.1, U8.12; also elsewhere on the board
/ROM-DIS1: R15.2, U12.6; also elsewhere on the board
/ROM-DIS2: R16.2, U12.5; also elsewhere on the board
/ROM-DIS3: R14.2, U12.12; also elsewhere on the board
/RUN: R28.2, U12.13; also elsewhere on the board
/S-BK: R22.1, U8.6; also elsewhere on the board
/S-UKNC: R20.2, U10.10; also elsewhere on the board
/WTB: R26.1, U10.4; also elsewhere on the board
GND: C17.1, C22.1, C23.1, Q2.2 (S), R14.1, R15.1, R16.1, R18.2, R19.2, R23.1, R24.2, R27.1, R28.1, U8.7 (GND), U10.7 (GND), U12.7 (V_{SS}); also elsewhere on the board
unnamed: D4.3, U10.6
unnamed: Q2.3 (D), X3.B5 (IRQ), X4.A10 (IRQ)
unnamed: Q2.1 (G), R24.1, R39.1
unnamed: R29.1, U12.4
unnamed: R30.1, U12.8
unnamed: R31.1, U12.11
unnamed: U8.3, X3.A23 (DIN), X4.A14 (DIN)
unnamed: U8.11, X3.B21 (DOUT), X4.B8 (DOUT)
unnamed: U8.8, X3.B20 (RPLY), X4.B15 (RPLY)
unnamed: U8.13, X3.B22 (SINC), X4.A15 (SINC)
unnamed: U10.3, X3.B11 (WTBT), X4.A8 (WTBT)
unnamed: U8.1, X3.A24 (IAKN2), X4.A5 (IAKN)
unnamed: D4.2, R19.1, U8.5, X3.B19 (INIT)
unnamed: R29.2, X3.A29 (BAS3-DIS)
unnamed: R30.2, X3.A14 (BAS-DIS)
unnamed: R31.2, X3.B1 (MON-DIS)
unnamed: D4.1, R18.1, U10.11, X4.B10 (INIT)
unnamed: U12.2, X4.A23 (RUN1)
unnamed: U12.1, X4.B2 (RUN2)
unnamed: R35.1, U10.9, X4.B14 (CE1)
unnamed: R36.1, U10.13, X4.B13 (CE2)
unnamed: R37.1, U10.1, X4.A12 (CE3)

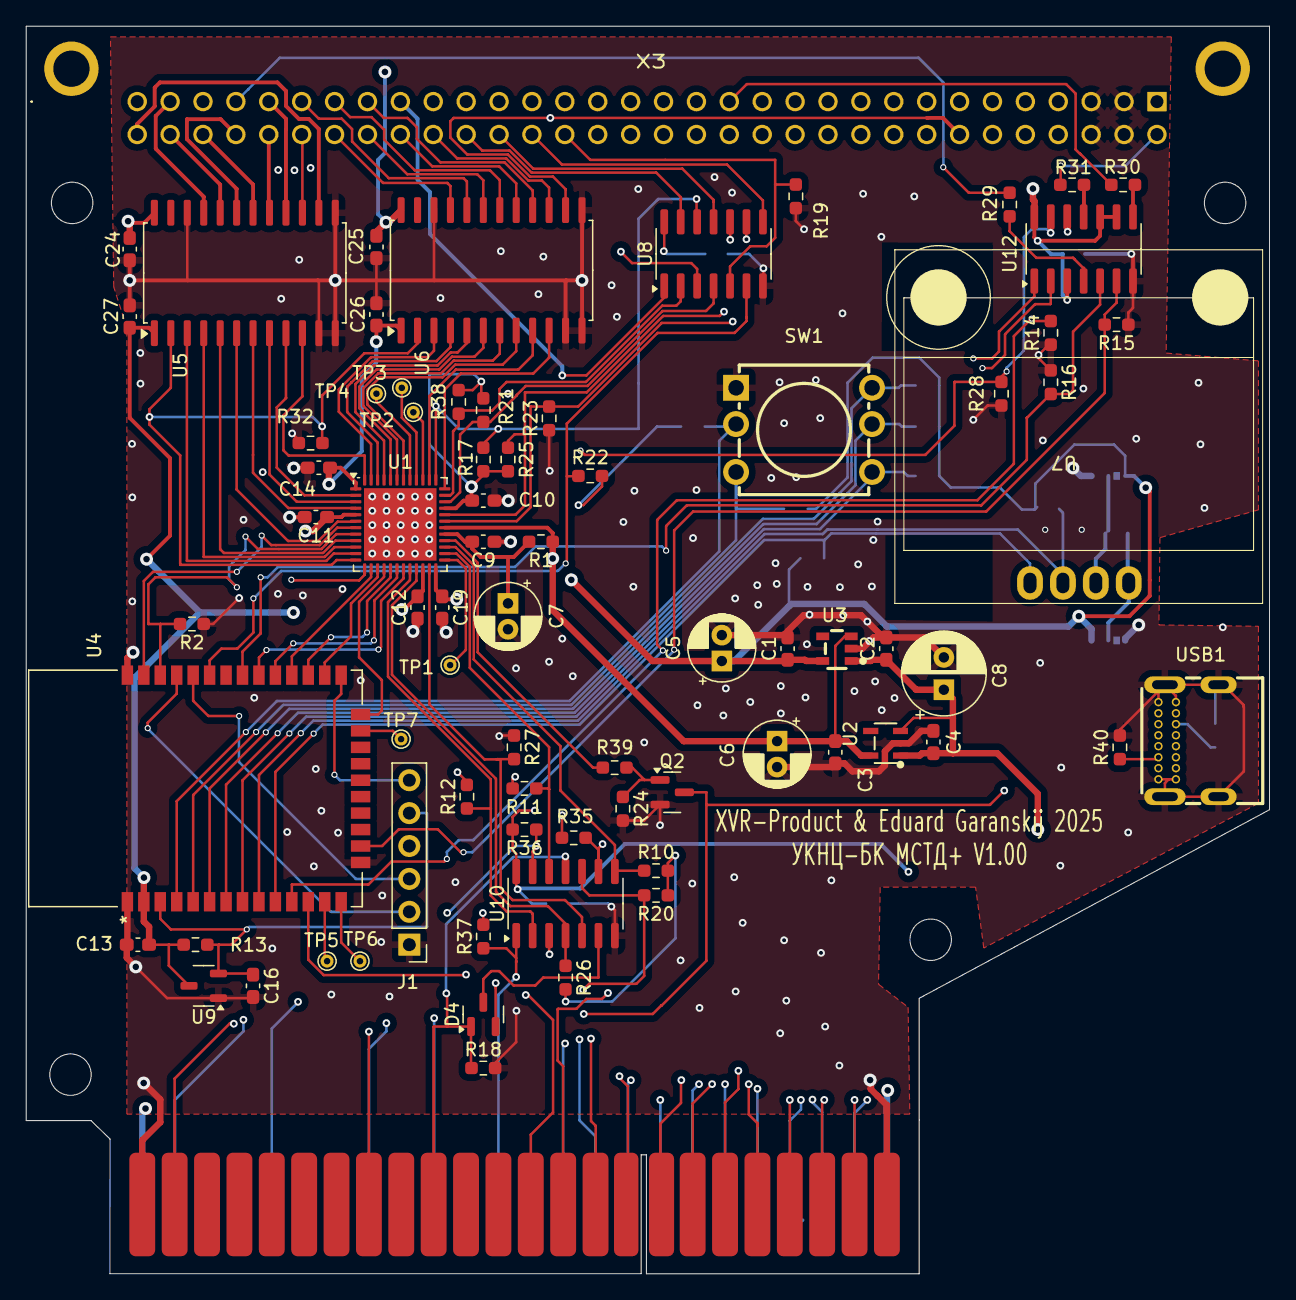
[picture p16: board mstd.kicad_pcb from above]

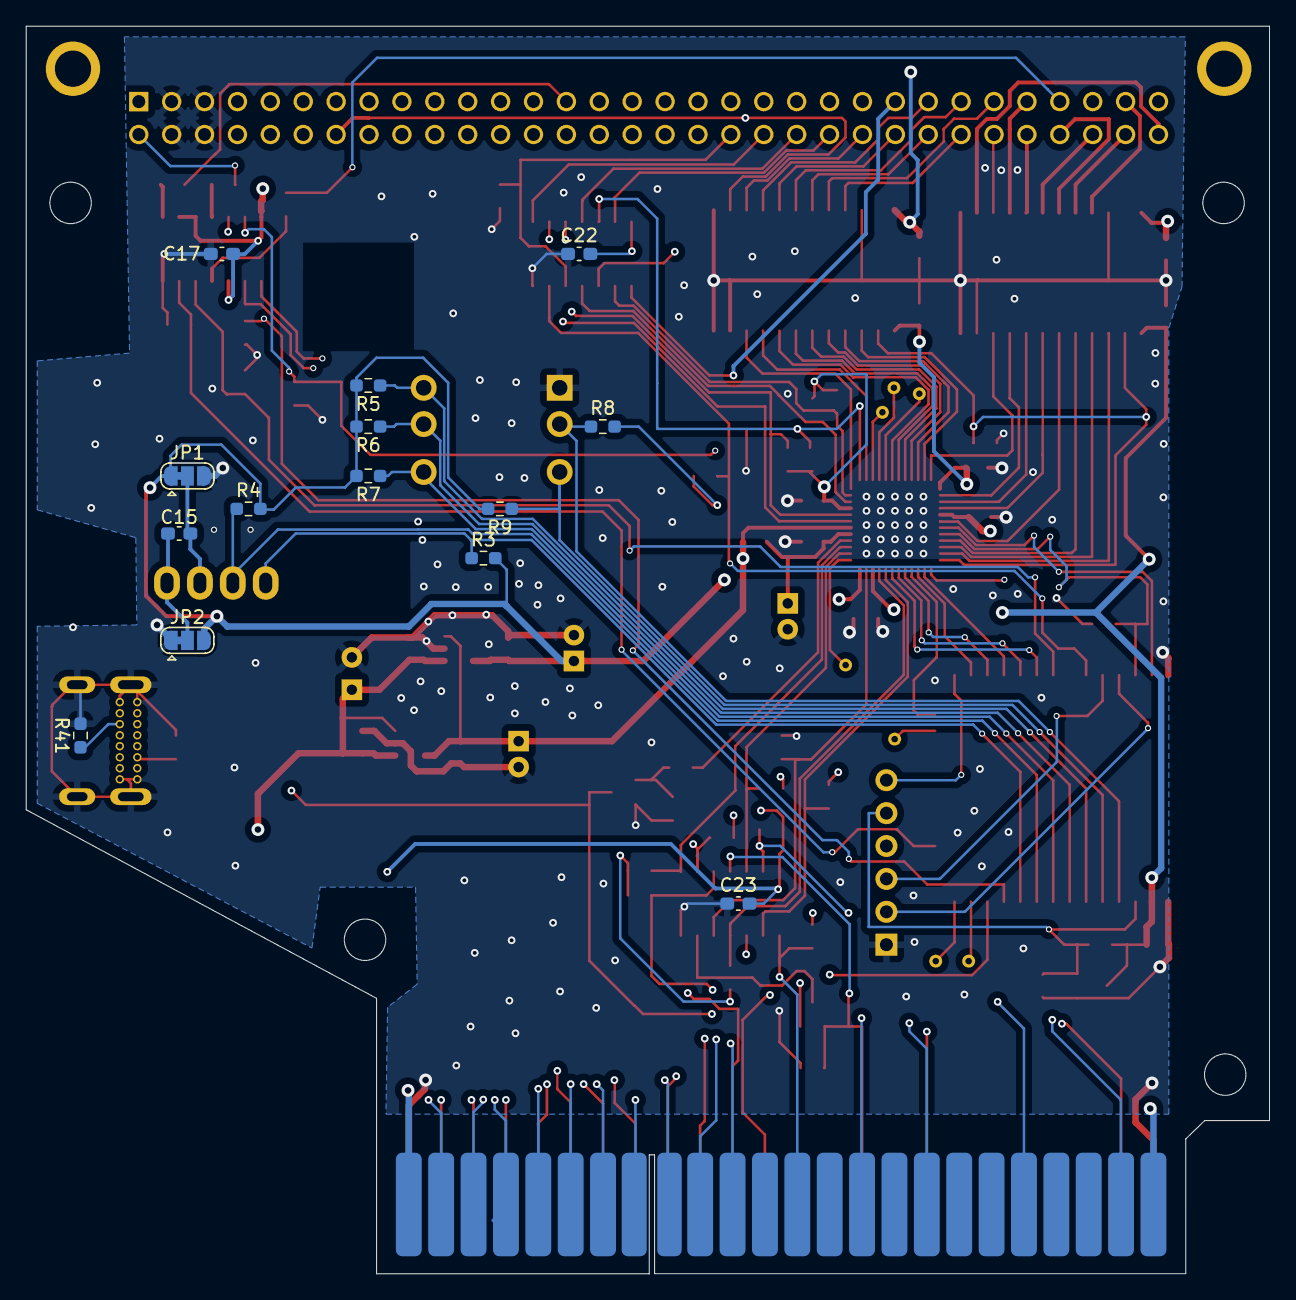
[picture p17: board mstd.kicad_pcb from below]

Board: 4 copper layers, 96.0 x 96.3 mm, 94 parts (14 on the bottom side), 107 nets.

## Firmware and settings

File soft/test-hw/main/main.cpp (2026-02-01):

#include "common.h"

#include "hardware.h"

extern "C" void app_main(void)
{
    hw_init();
    oled.draw_text(OLED_AP_ROW, "HW Test run");

    load_fpga();
    for(;;);
}

/*
void reboot()
{
    esp_task_wdt_config_t twdt_config = {
        .timeout_ms = 5000,
        .idle_core_mask = (1 << portNUM_PROCESSORS) - 1,    // Bitmask of all cores
        .trigger_panic = true
    };
    ESP_ERROR_CHECK(esp_task_wdt_init(&twdt_config));
    esp_task_wdt_add(NULL);
}
*/

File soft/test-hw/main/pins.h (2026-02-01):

#pragma once
                                     // Dir  Loader state
#define PIN_CDONE       GPIO_NUM_23  // in/PU in/PU
#define PIN_CRESET      GPIO_NUM_22  // out, zero
#define PIN_IOB29b      GPIO_NUM_18  // ?    in/PU
#define PIN_IOB31b      GPIO_NUM_5   // ?    in/PU

#define PIN_SPI_MISO    GPIO_NUM_17  // in   in/PU
#define PIN_SPI_MOSI    GPIO_NUM_16  // out  in/PU
#define PIN_SPI_SCK     GPIO_NUM_4   // out  in/PU
#define PIN_SPI_SS      GPIO_NUM_2   // out  in/PU

#define PIN_Left        GPIO_NUM_36  // in   in
#define PIN_Hit         GPIO_NUM_39  // in   in
#define PIN_Up          GPIO_NUM_34  // in   in
#define PIN_Right       GPIO_NUM_35  // in   in

#define PIN_Down        GPIO_NUM_32  // in   in
#define PIN_OLED_SCL    GPIO_NUM_33  // I2C SCL
#define PIN_OLED_SDA    GPIO_NUM_25  // I2C SDA
#define PIN_ROM_DIS3    GPIO_NUM_26  // out  in/PU
#define PIN_S_UKNC      GPIO_NUM_27  // in/PU in/PU
#define PIN_ROM_DIS1    GPIO_NUM_13  // out  in/PU
#define PIN_S_BK        GPIO_NUM_21  // in/PU in/PU
#define PIN_ROM_DIS2    GPIO_NUM_19  // out  in/PU

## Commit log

2025-06-07 FPGA pins swapped for bring SYNC to G* pin
    [io.kicad_sch, mstd.kicad_sch]
2025-06-07 Update schematic PDF
2025-06-07 Routing started
    [09031646951.stp, 09722646801.stp, cpu.kicad_sch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]
2025-06-07 Schematic in PDF updated
2025-06-08 Changed reset capacitor to 1.0
    [cpu.kicad_sch, mstd.kicad_pcb]
2025-06-08 Update Harting connector pin numeration to match SNP
    [io.kicad_sch, mstd.kicad_pcb, pwr.kicad_sch]
2025-06-11 Routhing in finilizing stage
    [io.kicad_sch, mstd.kicad_pcb, mstd.kicad_sch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]
2025-06-11 Routing finalized
    [mstd.kicad_pcb]
2025-06-12 Added version on PCB
    [mstd.kicad_pcb]
2025-06-16 Added GND vias
    [mstd.kicad_pcb]
2025-06-20 Fixes 74LVCX3245 package
    [mstd.kicad_pcb, mstd.kicad_sch]
2025-07-02 Finalized PCB
    [mstd.kicad_pcb, mstd.kicad_sch]
2025-11-01 Soft updated
    [mstd.kicad_sch, partitions_mstdp.csv]
2026-02-01 Added HW FPGA Test for ESP32 (FPGA Loader). FPGA Image not ready yet
    [partitions_mstdp.csv]
2026-02-05 Added pin list file (and C sensors data)
2026-02-07 Test FW run. Fix BootLoader placement
    [partitions_mstdp.csv]

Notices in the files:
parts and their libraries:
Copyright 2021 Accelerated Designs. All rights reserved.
